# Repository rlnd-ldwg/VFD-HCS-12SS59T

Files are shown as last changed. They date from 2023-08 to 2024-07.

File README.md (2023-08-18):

# Arduino Driver for Samsung HCS-12SS59T VFDisplay
quick and simple schematics, driver and example

## 

HCS-12SS59T in action

## Code
-> source directory

## Schematics
### Display
display schematics

- for simple DC filament supply  
  connect Vcc to VF+  
  mix normal and schottky diodes on VF- for desired voltage  
  keeping VF low extends tungsten filament lifetime  
  voltages starting with 2.7 V up to 3.6 V are working  
  do not exceed 125 mA!
- -> [AC Filament Supply](#ac-filament-supply) 

### Anode and Grid Supply
anode + grid supply schematics

- activate Vdisp  
  in VFD.h set `SUPPLYMODE 0`
- the simple _VDON with 1N4148 does not switch off Vdisp entirely,  
  maybe it can be omitted because the 470 ohm resistor on Vdisp  
  restricts current for VFD grid and anode

### AC Filament Supply
ac filament supply schematics

- activate Vdisp  https://electronics.stackexchange.com/questions/230044/help-driving-a-vfd-display
  in VFD.h set `SUPPLYMODE 0`
- extended filament endurance  
  (-> google filament notching)
- better brightness distribution  
  (theoretical, can't see any difference to DC supply on this display)
- coil-less

### Combined Clocked Supply
clocked supply schematics

- activate SUCLK_A/B  
  in VFD.h set `SUPPLYMODE 1`

## History
__V0.5__  
initial version  
__V0.6__  
AC filament supply  
__V0.7__  
AC filament supply _VDON  
__V0.8__  
AC filament supply polarity correction  
__V0.9__  
combined clocked supply

## Links
http://www.lapis-semi.com/en/data/datasheet-file_db/display/FEDL9289-01.pdf  
https://www.pollin.de/productdownloads/D121466D.PDF  
https://www.noritake-elec.com/technology/general-technical-information/vfd-operation  
http://www.kerrywong.com/2013/06/05/vfd-filament-driver-using-555/  
https://threeneurons.wordpress.com/vfd-stuff/
https://electronics.stackexchange.com/questions/230044/help-driving-a-vfd-display

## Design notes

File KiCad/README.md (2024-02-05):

# HCS-12SS59T
Driverboard for the Samsung VFD HCS-12SS59T

Borrowed schematic from https://github.com/qrti/VFD-HCS-12SS59T

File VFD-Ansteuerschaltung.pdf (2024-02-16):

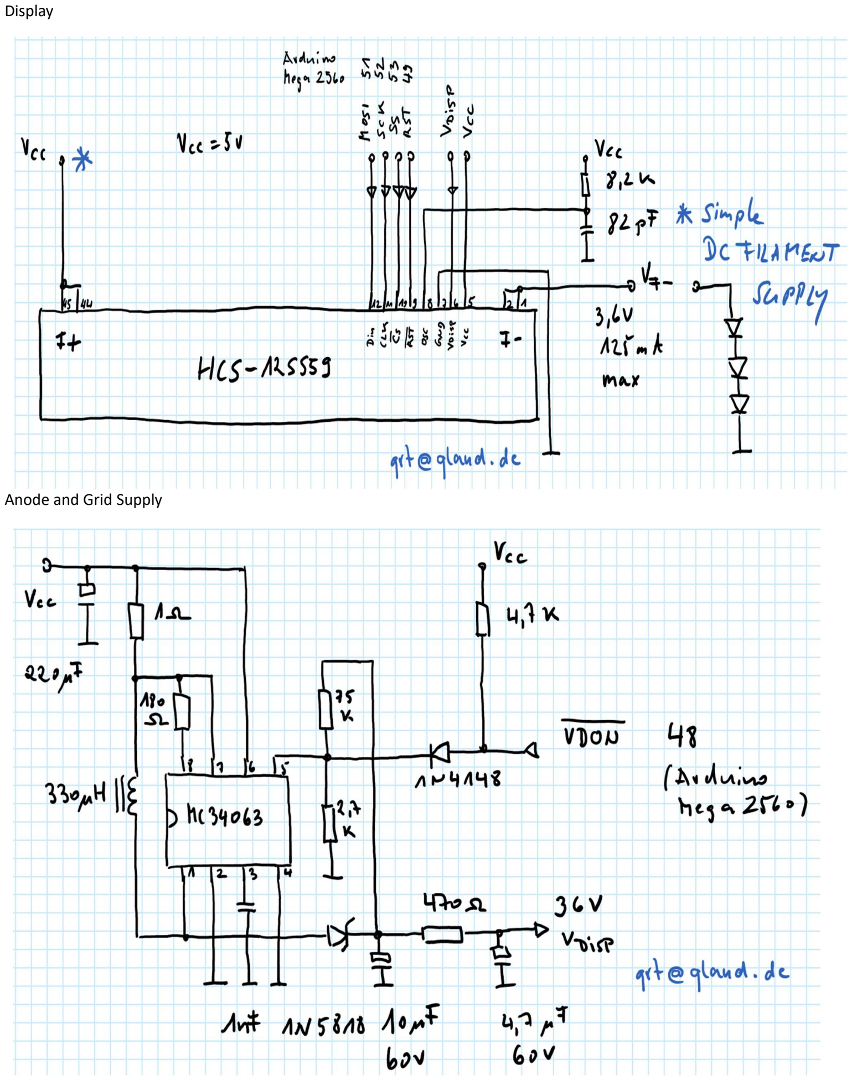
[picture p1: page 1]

Display

Anode and Grid Supply

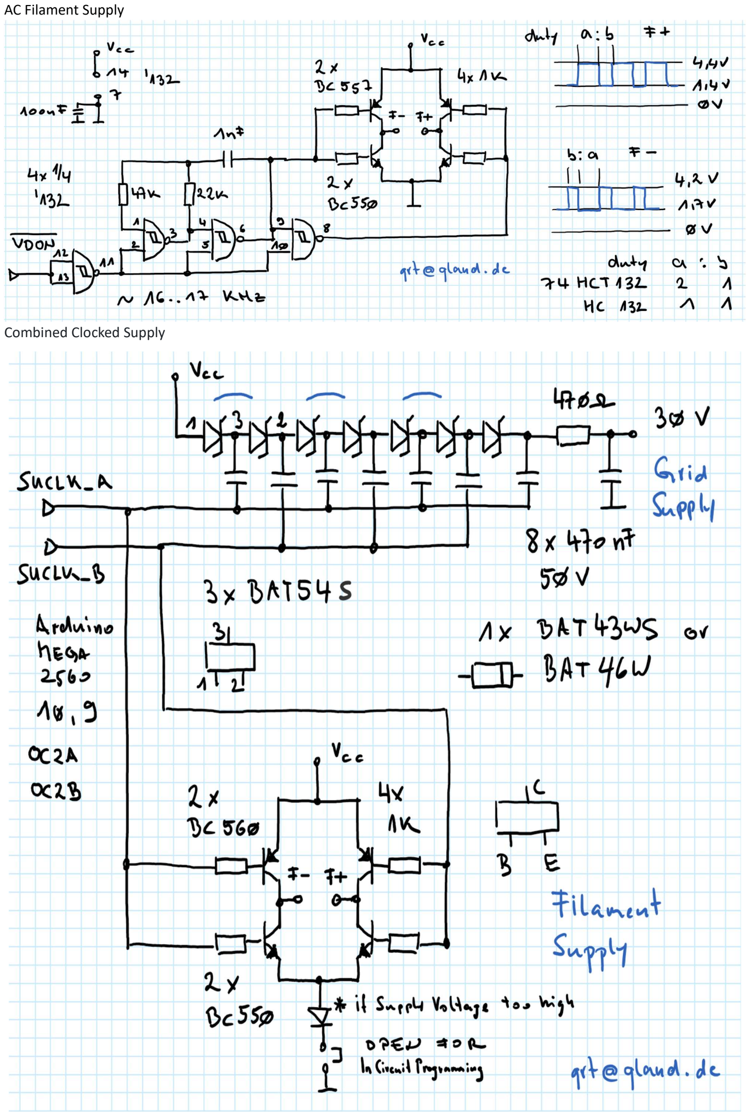
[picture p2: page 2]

AC Filament Supply

Combined Clocked Supply

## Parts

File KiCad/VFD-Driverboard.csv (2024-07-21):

ID | Bezeichner | Footprint | Stückzahl | Bezeichnung | Anbieter und Referenz
1 | R12 | R_1206_3216Metric_Pad1.30x1.75mm_HandSolder | 1 | 8k2
2 | H1,H4,H2,H3 | MountingHole_3.2mm_M3_ISO14580_Pad_TopBottom | 4 | MountingHole
3 | R11 | R_1206_3216Metric_Pad1.30x1.75mm_HandSolder | 1 | 1k8
4 | C9 | C_1206_3216Metric_Pad1.33x1.80mm_HandSolder | 1 | 82p
5 | J1 | PinSocket_1x08_P2.54mm_Vertical | 1 | MCU
6 | R5,R6 | R_1206_3216Metric_Pad1.30x1.75mm_HandSolder | 2 | 1k
7 | V1 | VFD HCS-12SS59T | 1 | ~
8 | R10 | R_1206_3216Metric_Pad1.30x1.75mm_HandSolder | 1 | 47k
9 | C8,C6 | CP_EIA-7343-31_Kemet-D_Pad2.25x2.55mm_HandSolder | 2 | 100uF
10 | R9 | R_1206_3216Metric_Pad1.30x1.75mm_HandSolder | 1 | 180
11 | C4,C5,C3,C1 | C_2220_5750Metric_Pad1.97x5.40mm_HandSolder | 4 | 1u
12 | D3 | D_2010_5025Metric_Pad1.52x2.65mm_HandSolder | 1 | D
13 | U1 | SOIC127P599X175-8N | 1 | MC34063AD
14 | R3 | R_1206_3216Metric_Pad1.30x1.75mm_HandSolder | 1 | 2k2
15 | TP1 | TestPoint_Pad_D2.5mm | 1 | Vee
16 | R2,R1,R4 | R_1206_3216Metric_Pad1.30x1.75mm_HandSolder | 3 | 10k
17 | TP2 | TestPoint_Pad_D2.5mm | 1 | F-
18 | D2 | D_SOD-123 | 1 | 1N5819
19 | TP3 | TestPoint_Pad_D2.5mm | 1 | F+
20 | C2 | C_1206_3216Metric_Pad1.33x1.80mm_HandSolder | 1 | 10n
21 | L1 | IND_TAIYO_NRS8040_TAY | 1 | 100uH
22 | R7 | R_1206_3216Metric_Pad1.30x1.75mm_HandSolder | 1 | 100k
23 | C7 | C_1206_3216Metric_Pad1.33x1.80mm_HandSolder | 1 | 270pF
24 | U2 | SOIC127P599X175-8N | 1 | LM4871MX_NOPB
25 | R8 | R_1206_3216Metric_Pad1.30x1.75mm_HandSolder | 1 | 1
26 | D1 | D_2010_5025Metric_Pad1.52x2.65mm_HandSolder | 1 | 2V7

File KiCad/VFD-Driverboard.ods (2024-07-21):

ID | Bezeichner | Footprint | Stückzahl | Bezeichnung | Anbieter und Referenz
1 | C2 | C_1206_3216Metric_Pad1.33x1.80mm_HandSolder | 1 | 10n
2 | C7 | C_1206_3216Metric_Pad1.33x1.80mm_HandSolder | 1 | 330pF
3 | C9 | C_1206_3216Metric_Pad1.33x1.80mm_HandSolder | 1 | 82p
4 | C4,C5,C3,C1 | C_2220_5750Metric_Pad1.97x5.40mm_HandSolder | 4 | 1u
5 | C8,C6 | CP_EIA-7343-31_Kemet-D_Pad2.25x2.55mm_HandSolder | 2 | 100uF
6 | D1 | D_2010_5025Metric_Pad1.52x2.65mm_HandSolder | 1 | 2V7
7 | D3 | D_2010_5025Metric_Pad1.52x2.65mm_HandSolder | 1 | D
8 | D2 | D_SOD-123 | 1 | 1N5819
9 | L1 | IND_TAIYO_NRS8040_TAY | 1 | 100uH
10 | H1,H4,H2,H3 | MountingHole_3.2mm_M3_ISO14580_Pad_TopBottom | 4 | MountingHole
11 | J1 | PinSocket_1x08_P2.54mm_Vertical | 1 | MCU
12 | R10 | R_1206_3216Metric_Pad1.30x1.75mm_HandSolder | 1 | 47k
13 | R11 | R_1206_3216Metric_Pad1.30x1.75mm_HandSolder | 1 | 1k8
14 | R12 | R_1206_3216Metric_Pad1.30x1.75mm_HandSolder | 1 | 1
15 | R2,R1,R4 | R_1206_3216Metric_Pad1.30x1.75mm_HandSolder | 3 | 10k
16 | R3 | R_1206_3216Metric_Pad1.30x1.75mm_HandSolder | 1 | 2k2
17 | R5,R6 | R_1206_3216Metric_Pad1.30x1.75mm_HandSolder | 2 | 1k
18 | R7 | R_1206_3216Metric_Pad1.30x1.75mm_HandSolder | 1 | 100k
19 | R8 | R_1206_3216Metric_Pad1.30x1.75mm_HandSolder | 1 | 1
20 | R9 | R_1206_3216Metric_Pad1.30x1.75mm_HandSolder | 1 | 100
21 | U1 | SOIC127P599X175-8N | 1 | MC34063AD
22 | U2 | SOIC127P599X175-8N | 1 | LM4871MX_NOPB
23 | TP1 | TestPoint_Pad_D2.5mm | 1 | Vee
24 | TP2 | TestPoint_Pad_D2.5mm | 1 | F-
25 | TP3 | TestPoint_Pad_D2.5mm | 1 | F+
26 | V1 | VFD HCS-12SS59T | 1 | ~

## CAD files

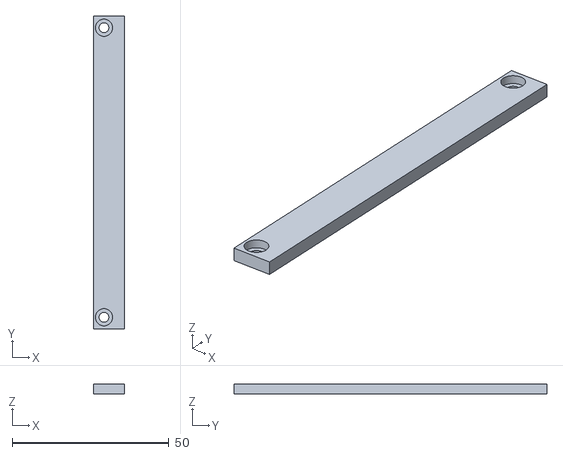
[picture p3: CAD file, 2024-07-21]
spacer_VFD.stl
10.0 x 100.0 x 3.20

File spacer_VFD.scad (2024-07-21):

/*
 * spacer for VFD  Samsung HCS-12SS59T
 */

// global parameters
$fn = 1000;
co = 0.01;
_2co = 2 * co;
debug = false;

spacer = [10.0, 100.0, 3.2];
hole_dist = 92.5;
hole_dia = 3.2;
countersunk_depth = 2.0; 
countersunk_dia = 5.75;

dist2edge = [3.4, (spacer.y - hole_dist) / 2];



difference(){
    cube(spacer);
    translate([dist2edge.x, dist2edge.y, -co])
    cylinder(h = spacer.z + _2co, d = hole_dia);
    translate([dist2edge.x, dist2edge.y, spacer.z - countersunk_depth])
    cylinder(h = countersunk_depth + _2co, d = countersunk_dia);
    translate([dist2edge.x, spacer.y - dist2edge.y, -co])
    cylinder(h = spacer.z + _2co, d = hole_dia);
    translate([dist2edge.x, spacer.y - dist2edge.y, spacer.z - countersunk_depth])
    cylinder(h = countersunk_depth + _2co, d = countersunk_dia);
}

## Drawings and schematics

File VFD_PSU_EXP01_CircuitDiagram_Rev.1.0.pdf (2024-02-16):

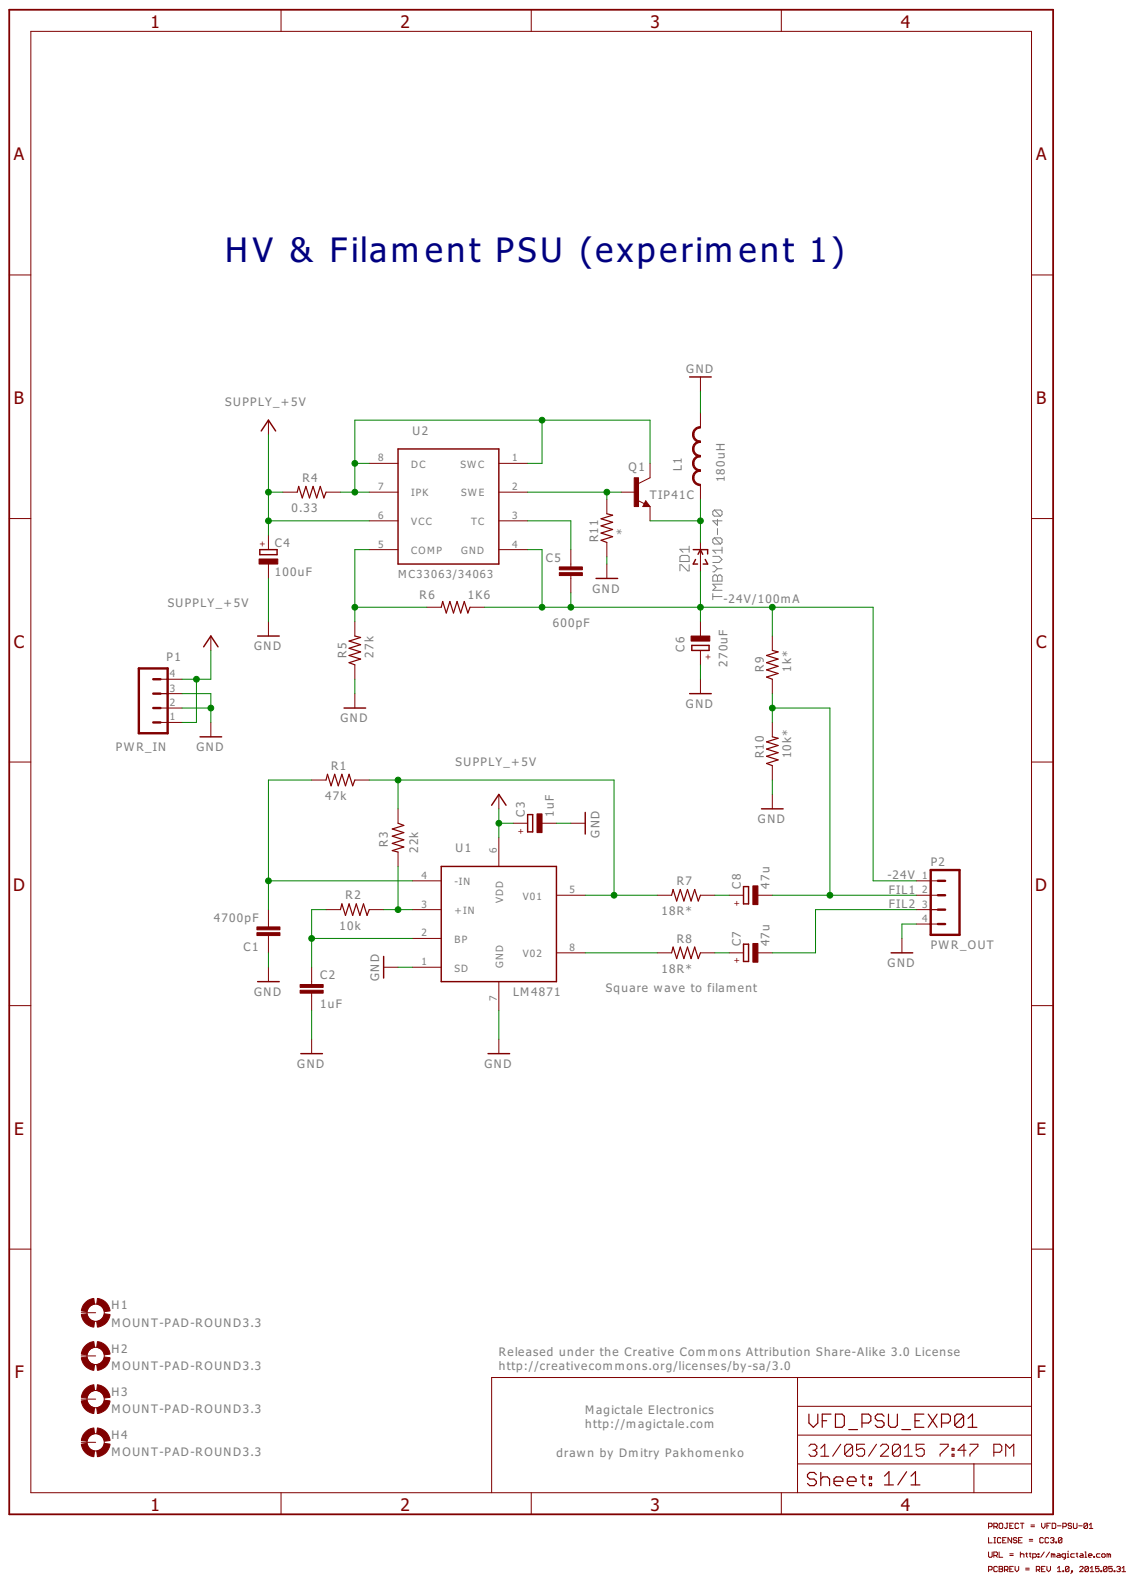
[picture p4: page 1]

HV & Filament PSU (experiment 1)

Square wave to filament

MOUNT-PAD-ROUND3.3 MOUNT-PAD-ROUND3.3

Released under the Creative Commons Attribution Share-Alike 3.0 License http://creativecommons.org/licenses/by-sa/3.0

Magictale Electronics http://magictale.com

drawn by Dmitry Pakhomenko

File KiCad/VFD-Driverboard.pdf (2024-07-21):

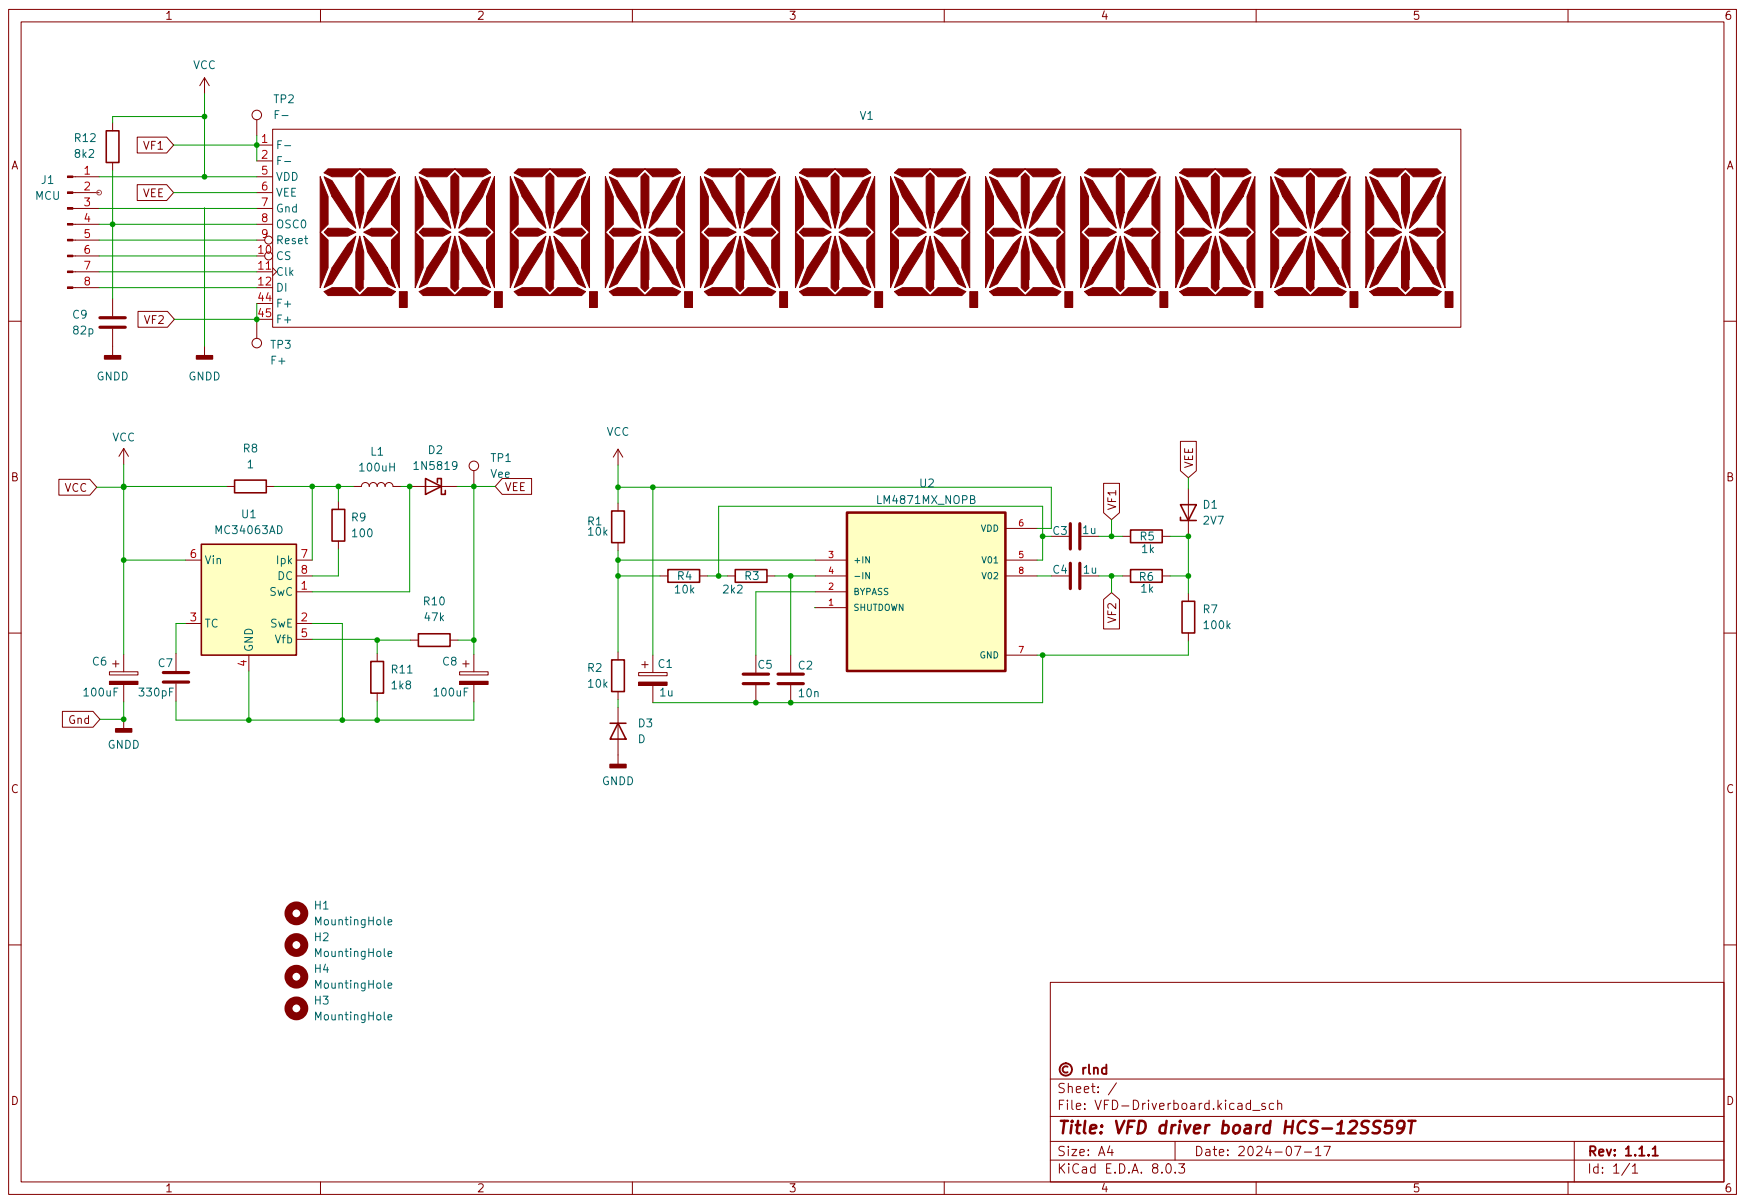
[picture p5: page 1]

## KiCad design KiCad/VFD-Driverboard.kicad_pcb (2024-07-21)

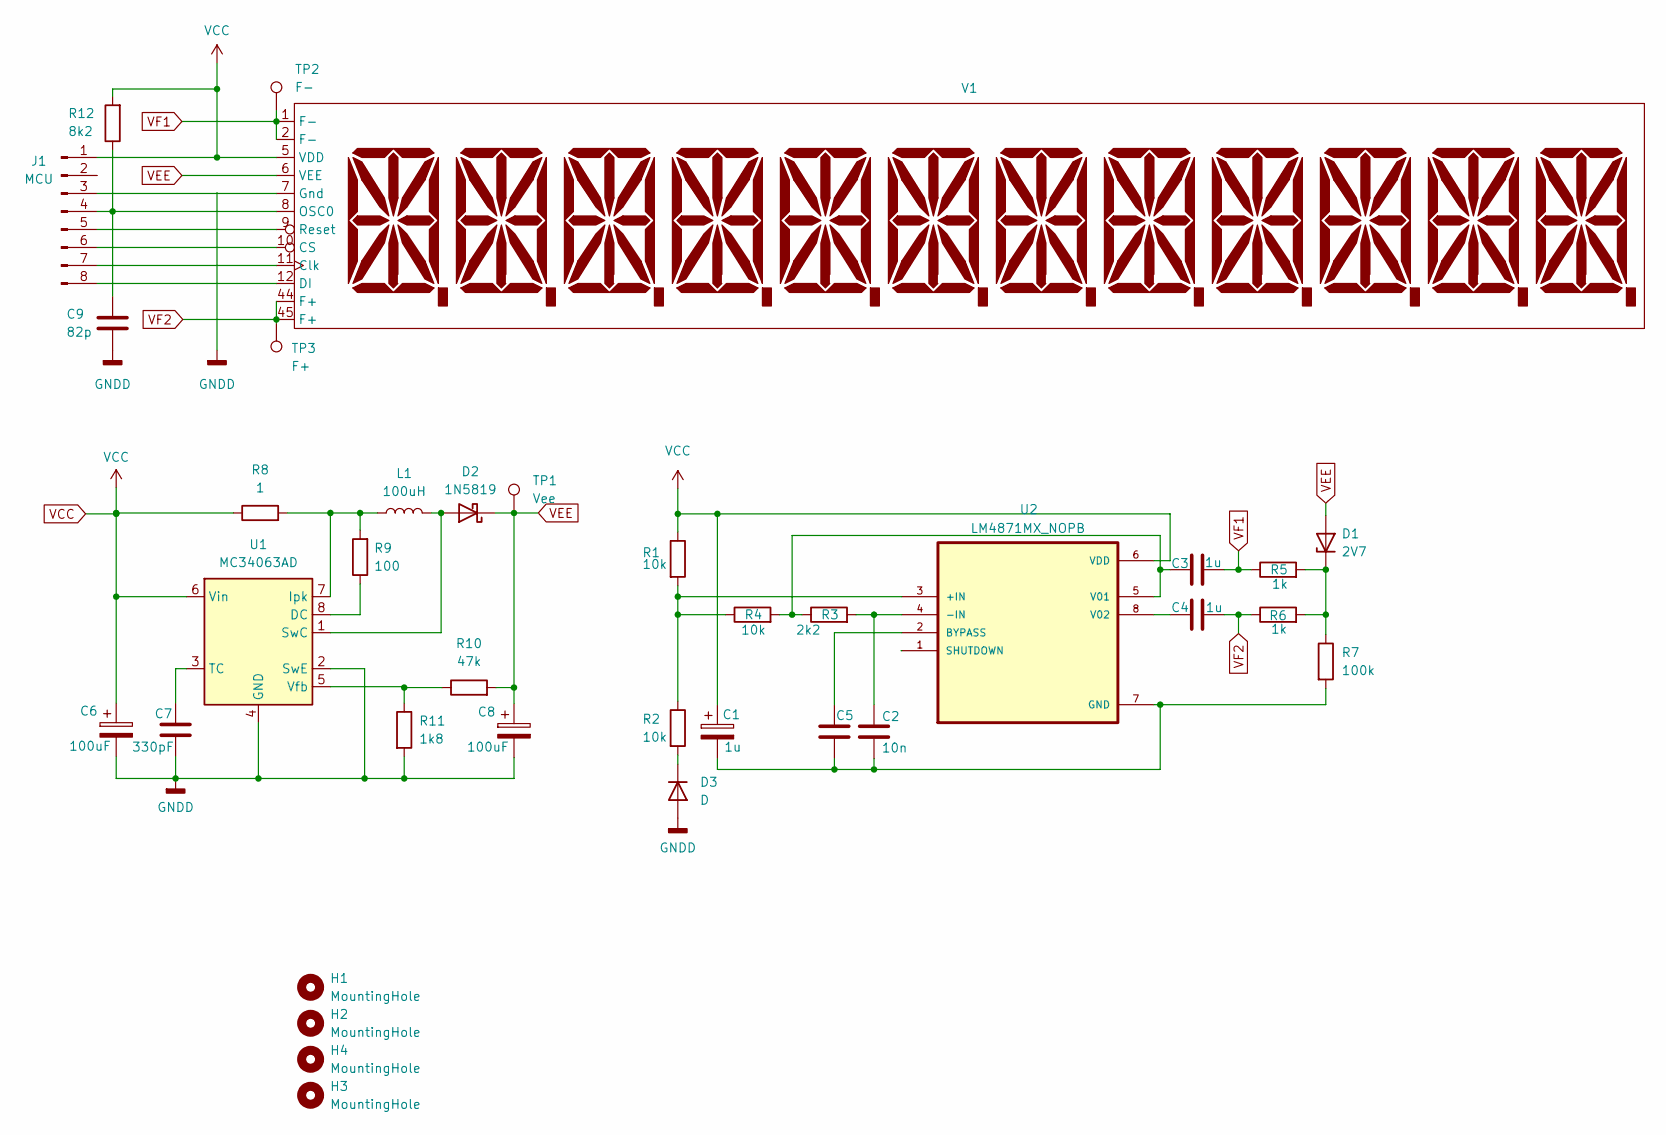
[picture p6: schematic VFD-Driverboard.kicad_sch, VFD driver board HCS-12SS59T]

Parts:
C1, C3, C4, C5: 1u; C_2220_5750Metric_Pad1.97x5.40mm_HandSolder
C2: 10n; C_1206_3216Metric_Pad1.33x1.80mm_HandSolder
C6, C8: 100uF; CP_EIA-7343-31_Kemet-D_Pad2.25x2.55mm_HandSolder
C7: 330pF; C_1206_3216Metric_Pad1.33x1.80mm_HandSolder
C9: 82p; C_1206_3216Metric_Pad1.33x1.80mm_HandSolder
D1: 2V7; D_2010_5025Metric_Pad1.52x2.65mm_HandSolder
D2: 1N5819; D_SOD-123
D3: D; D_2010_5025Metric_Pad1.52x2.65mm_HandSolder
H1, H2, H3, H4: MountingHole; MountingHole_3.2mm_M3_ISO14580_Pad_TopBottom
J1: MCU; PinSocket_1x08_P2.54mm_Vertical
L1: 100uH; IND_TAIYO_NRS8040_TAY
R1, R2, R4: 10k; R_1206_3216Metric_Pad1.30x1.75mm_HandSolder
R3: 2k2; R_1206_3216Metric_Pad1.30x1.75mm_HandSolder
R5, R6: 1k; R_1206_3216Metric_Pad1.30x1.75mm_HandSolder
R7: 100k; R_1206_3216Metric_Pad1.30x1.75mm_HandSolder
R8: 1; R_1206_3216Metric_Pad1.30x1.75mm_HandSolder
R9: 100; R_1206_3216Metric_Pad1.30x1.75mm_HandSolder
R10: 47k; R_1206_3216Metric_Pad1.30x1.75mm_HandSolder
R11: 1k8; R_1206_3216Metric_Pad1.30x1.75mm_HandSolder
R12: 8k2; R_1206_3216Metric_Pad1.30x1.75mm_HandSolder
TP1: Vee; TestPoint_Pad_D2.5mm
TP2: F-; TestPoint_Pad_D2.5mm
TP3: F+; TestPoint_Pad_D2.5mm
U1: MC34063AD; SOIC127P599X175-8N
U2: LM4871MX_NOPB; SOIC127P599X175-8N
V1: VFD HCS-12SS59T

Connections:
unnamed: D1.1 (K), R5.2, R6.2, R7.1
unnamed: D2.2 (A), L1.2, U1.1 (SwC)
unnamed: D3.1 (K), R2.2
unnamed: J1.3, V1.7 (Gnd)
unnamed: C9.2, J1.4, R12.1, V1.8 (OSC0)
unnamed: J1.5, V1.9 (Reset)
unnamed: J1.6, V1.10 (CS)
unnamed: J1.7, V1.11 (Clk)
unnamed: J1.8, V1.12 (DI)
unnamed: R9.1, U1.8 (DC)
unnamed: L1.1, R8.2, R9.2, U1.7 (Ipk)
unnamed: C7.1, U1.3 (TC)
unnamed: R10.1, R11.1, U1.5 (Vfb)
unnamed: R1.2, R2.1, R4.1, U2.3 (+IN)
unnamed: C2.1, R3.2, U2.4 (-IN)
unnamed: C5.1, U2.2 (BYPASS)
unnamed: C1.2, C2.2, C5.2, R7.2, U2.7 (GND)
unnamed: C3.1, R3.1, R4.2, U2.5 (V01)
unnamed: C4.1, U2.8 (V02)
VCC: C1.1, C6.1, J1.1, R1.1, R8.1, R12.2, U1.6 (Vin), U2.6 (VDD), V1.5 (VDD)
VEE: C8.1, D1.2 (A), D2.1 (K), R10.2, TP1.1, V1.6 (VEE)
VF1: C3.2, R5.1, TP2.1, V1.1 (F-), V1.2 (F-)
VF2: C4.2, R6.1, TP3.1, V1.44 (F+), V1.45 (F+)

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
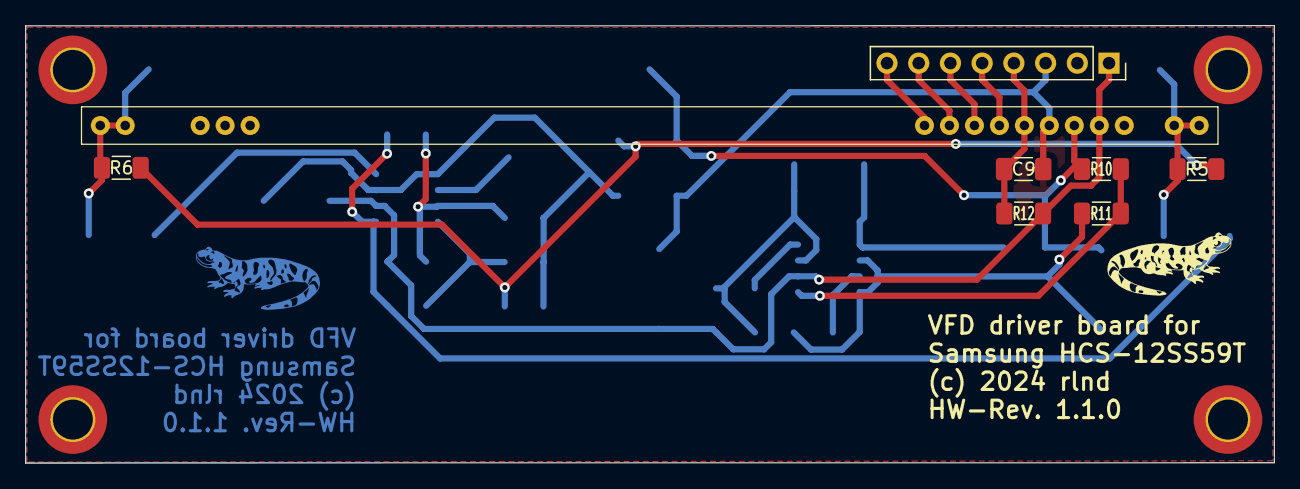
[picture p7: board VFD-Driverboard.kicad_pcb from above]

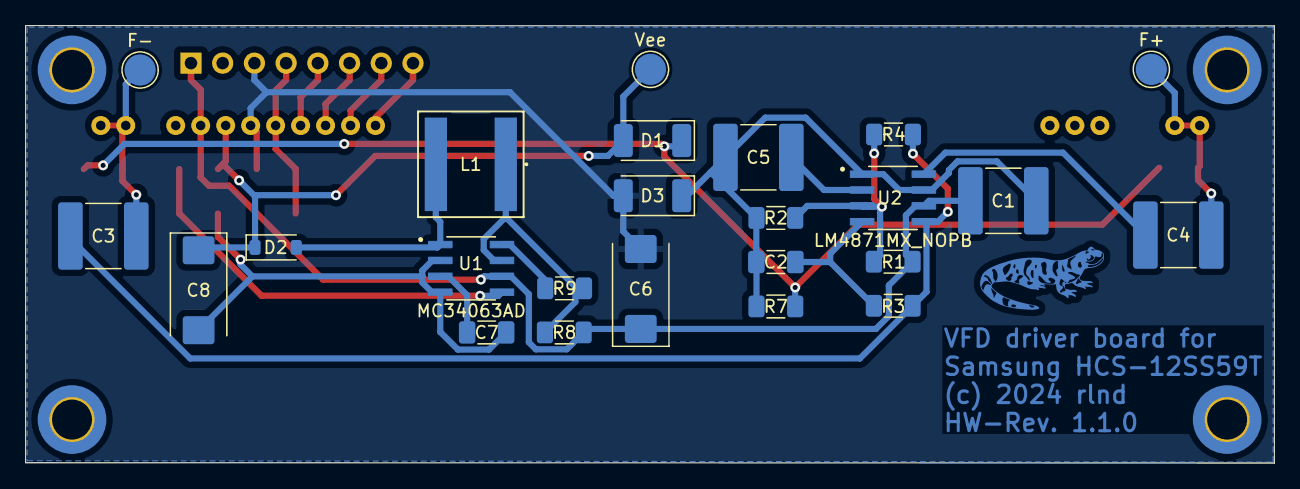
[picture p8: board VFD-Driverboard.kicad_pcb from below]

Board: 2 copper layers, 100.0 x 35.0 mm, 36 parts (24 on the bottom side), 25 nets.

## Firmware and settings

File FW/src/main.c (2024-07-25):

/*
 * test programm VFD display Samsung HCS-12SS59T
 *
 * (c) Juli 2024 by Roland Ludwig
 *
 *  v0.2.0
 * 
 * 2024/07/24 ????
 * 
 */

#define F_CPU 12000000  // ATmega8 Testboard Ulrich Radig

#include <avr/io.h>
#include <util/delay.h>
#include "../include/spi.h"
#include "../include/vfd.h"

int main(void)
{
    uint8_t i;

    VFD_DDR |= (1 << LED);
    for (i = 1; i < 8; i++)
        VFD_PORT ^= (1 << LED);
        _delay_ms(200);
    }

    VFD_Init();

    VFD_Display("Das ist Test");
    
    while (1){
        
        VFD_PORT ^= (1 << LED);
        _delay_ms(500);
    }
} // main

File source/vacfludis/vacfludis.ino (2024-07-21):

// VFD.cpp, vacuum fluroescent example for Samsung HCS-12SS59T, V0.9 171112 qrt@qland.de

//#include <Arduino.h>

#include "VFD.h"

void setup()
{
	//pinMode(Pin_RED_LED13, OUTPUT);
	//digitalWrite(Pin_RED_LED13, HIGH);
  pinMode(LED_BUILTIN, OUTPUT);
	Serial.begin(9600);
//	Vfd.init();

//	Vfd.write("QRT@QLAND_DE * ABCDEFGHIJKLMNOPQRSTUVWXYZ * 0123456789 * ");		// display 
	//Vfd.scroll(20);																// scroll left  (+) 20 * 0.01 chars per second*/
}																				//        right (-)
																				//        stop  (0)
void loop()
{
																// scroll left  (+) 20 * 0.01 chars per second
  digitalWrite(LED_BUILTIN, HIGH);  // turn the LED on (HIGH is the voltage level)
  delay(1000);                      // wait for a second
  digitalWrite(LED_BUILTIN, LOW);   // turn the LED off by making the voltage LOW
  delay(1000);                      // wait for a second
}

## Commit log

2023-08-18 Schematic and board added
    [vfddriver.brd]
2024-02-05 Datasheets / Schematic, PCB
    [vfddriver.brd]
2024-02-05 KiCad Files
    [VFD-Driverboard.kicad_pcb, VFD-Driverboard.kicad_sch, vfddriver.brd]
2024-02-16 KiCad schematic
    [VFD-Driverboard.kicad_pcb, VFD-Driverboard.kicad_sch, vfddriver.brd]
2024-02-17 Schematic 1.0.6
2024-02-18 PCB & Gerber files
    [VFD-Driverboard-B_Cu.gbr, VFD-Driverboard-B_Mask.gbr, VFD-Driverboard-B_Paste.gbr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]
2024-02-21 Driverboard v. 1.0.4
    [VFD-Driverboard-B_Cu.gbr, VFD-Driverboard-B_Mask.gbr, VFD-Driverboard-B_Paste.gbr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]
2024-03-01 KiCad Directory renamed
    [VFD-Driverboard-B_Cu.gbr, VFD-Driverboard-B_Mask.gbr, VFD-Driverboard-B_Paste.gbr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]
2024-03-01 Removed old direktory
    [VFD-Driverboard-B_Cu.gbr, VFD-Driverboard-B_Mask.gbr, VFD-Driverboard-B_Paste.gbr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]
2024-07-08 SMD PCB
    [MC34063.ods, MC34063.old.ods]
2024-07-08 PCB / tidy up
    [MC34063.ods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]
2024-07-08 new PCB
    [VFD-Driverboard-B_Cu.gbr, VFD-Driverboard-B_Mask.gbr, VFD-Driverboard-B_Paste.gbr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]
2024-07-08 tidy up
    [VFD-Driverboard-NPTH.drl, VFD-Driverboard-PTH.drl]
2024-07-21 added MPLAB project
    [VFD-Driverboard.csv, VFD-Driverboard.kicad_pcb, VFD-Driverboard.kicad_sch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]
2024-07-23 changes SPI interface
2024-07-24 SPI routines
2024-07-25 spi/vfd interface

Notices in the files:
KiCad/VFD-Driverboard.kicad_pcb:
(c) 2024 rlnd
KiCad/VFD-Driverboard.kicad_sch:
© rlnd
